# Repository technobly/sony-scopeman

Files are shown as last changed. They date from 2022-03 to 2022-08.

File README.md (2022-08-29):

# Sony-Scopeman

Hardware Design files of a replacement mainboard for the Sony Watchman FD-10A. This turns it into a bluetooth and Wi-Fi-enabled vector display.

# Features
There are two modes which can be selected via the power switch:

* In "Audio" mode, the ESP32 acts as a bluetooth speaker. Play back audio files from your smartphone or laptop to hear and see the soundwaves. You can change the size by adjusting the playback volume

    [Audio Demo](https://twitter.com/FauthNiklas/status/1337467949318279170)

* In "Video" mode, the ESP32 renders the result of the Lorenz Attractor equation. You can change the simulation speed using the "Tune" knob.

    [Video Demo](https://twitter.com/FauthNiklas/status/1339650704584171522)

# Instructions

You'll need:

* Sony Watchman Model FD-10A
* Pre-assembled replacemend mainboard (eg. from JLCPCB assembly)
* Two 803040 (1000mAh) Lipo batteries with JST-PH 2.0mm connector



Open the Sony Watchman and unscrew the original mainboard. Make sure to keep all the screws in a safe place.



Unsolder all wires from the mainboard.



Unsolder (and unscrew) these components from the mainboard. We'll need them for our replacement.




Your trimmer pots might also be a different style, but check that they are the same 5k ohm value ("502").

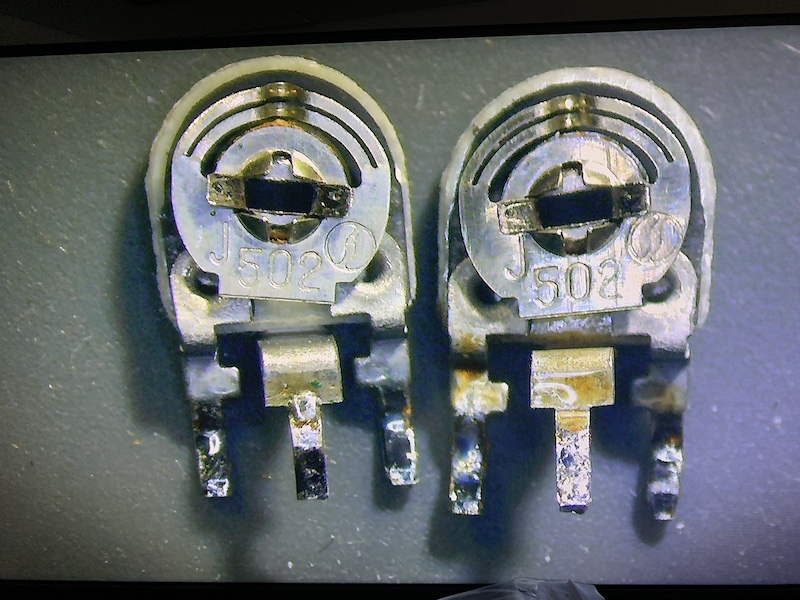
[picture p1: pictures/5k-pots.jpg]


Install all unsoldered components on the replacement mainboard.



Unsolder the speaker cables (black and white) from the flyback PCB. Solder them to the replacement PCB (take care of polarity. White is closer to the ESP32).
Remove all other cables from the flyback PCB except for blue, yellow, black and purple.



Your speaker wires might not be black and white, but both black.  There is a polarity of the speaker, and the positive (+) was marked with red paint/glyptol.  You might also have to extend your speaker wires.

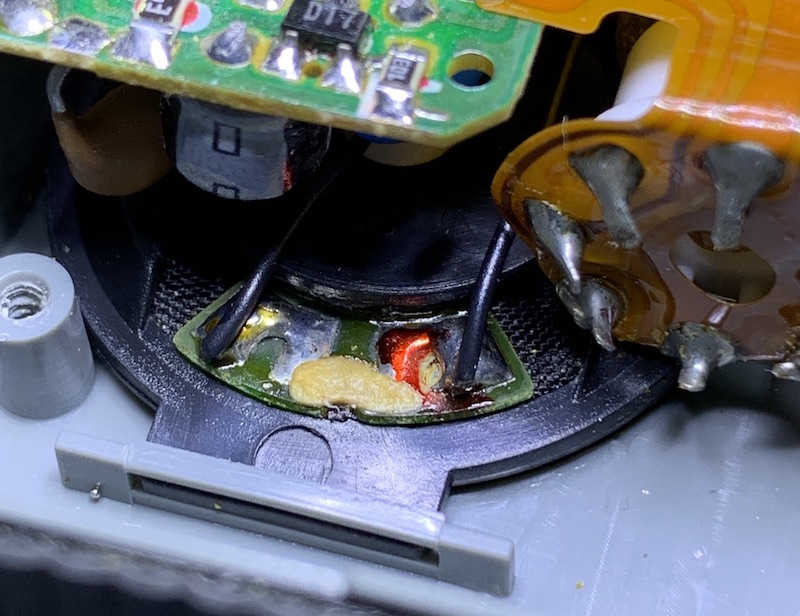
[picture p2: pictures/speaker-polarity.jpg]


Solder the blue (flyback signal) and yellow (blanking) to the new mainboard.
Do the same for purple (supply) and black (GND).



Next, connect the deflection coil wires (purple, white, red and blue). 



Here are more pictures of the assembled unit.
:mag: CLICK FOR A LARGER IMAGE!

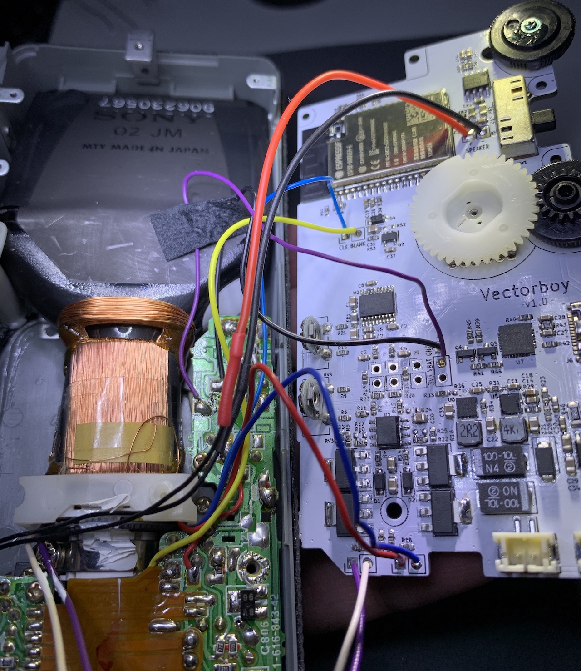
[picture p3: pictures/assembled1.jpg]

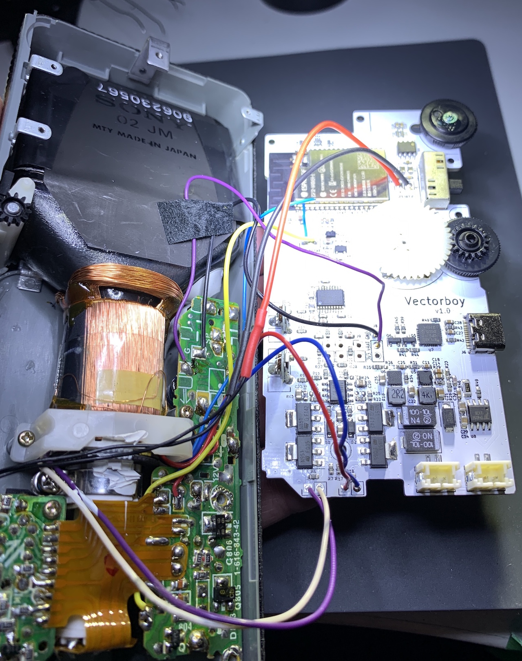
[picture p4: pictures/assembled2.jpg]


:pencil2: If you want to slowly bring up your board and not let the magic smoke out, here are some things you can do:

- Use a current limited power supply and make a cable that plugs into the JST2.0 connector.  Set your power supply to 4V at 500mA.
- When the device normally powers on it draws about 300mA.  If it draws 500mA you probably have a short circuit somewhere.
- Check the +3.3V output (it should be about +3.3V)
- Check the -3.3V output (it should be about -3.7V)
- :warning: Check the FLYBACK output, it should be toggling at 16kHz @ 40% duty cycle.  If it's continuously LOW, it will make the power supply draw infinite amounts of current.  It should be pulled up to +3.3V when the ESP32 is reset/programming via R50.

You'll proabably want to play with it for a while and make sure everything is working well before moving on to the final steps.

You can now plug in the batteries (make sure the watchman is turned off) and screw the mainboard back in place. You need two screws for this (mind the arrows on the back of the PCB).


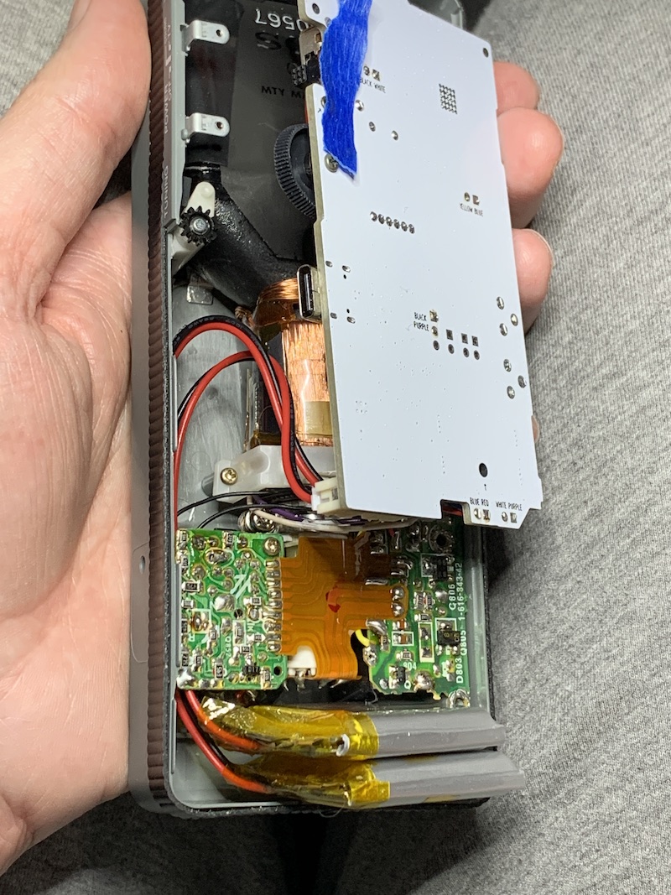
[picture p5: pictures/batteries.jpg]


Now you can add a slothole to the lower half of the case for the USB type C jack. You also need to brake away some plastics to make space for the new batteries. No worries, if done correctly this won't be visible from the outside and the battery cover will still close.

Something really handy for these mods is the [Dremel 1/16" ballnose cutter (#109)](https://www.amazon.com/Dremel-109-Engraving-Cutter-16-inch/dp/B0006N72X4).  I got mine in an [11 piece Carving/Engraving Kit](https://www.amazon.com/Dremel-729-01-Engraving-Accessories-11-Piece/dp/B09FP387V2).  This is also really good for the USB-C cut-out.


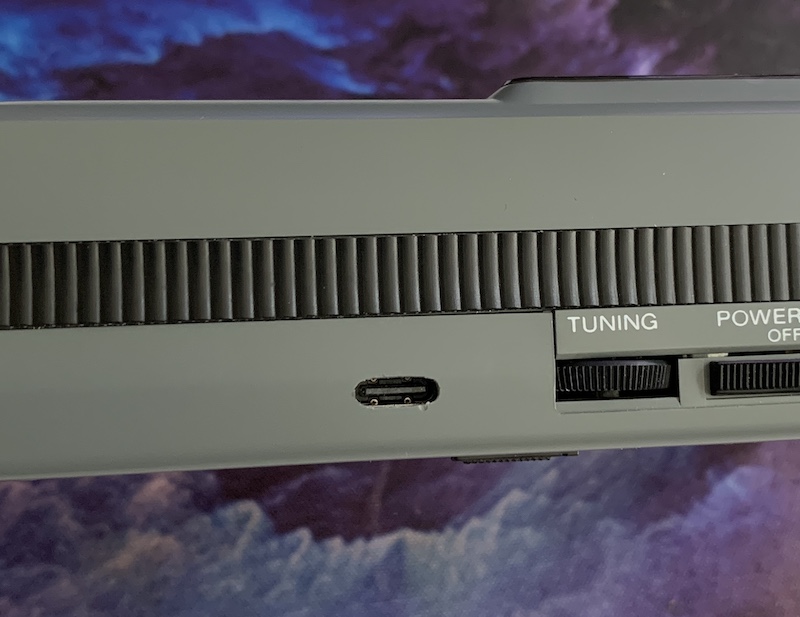
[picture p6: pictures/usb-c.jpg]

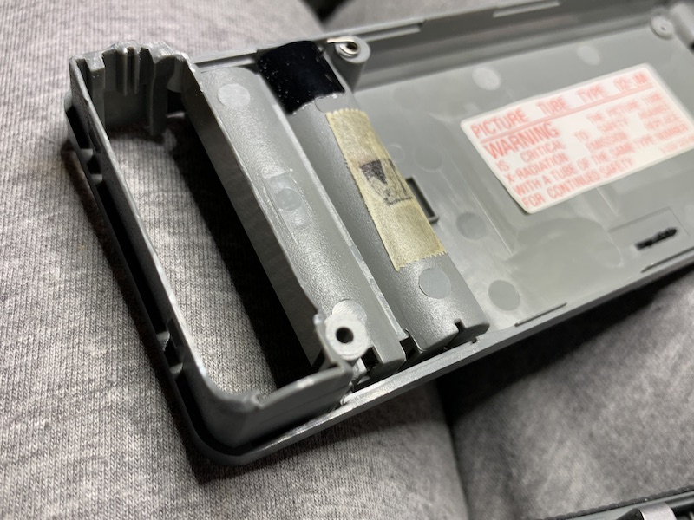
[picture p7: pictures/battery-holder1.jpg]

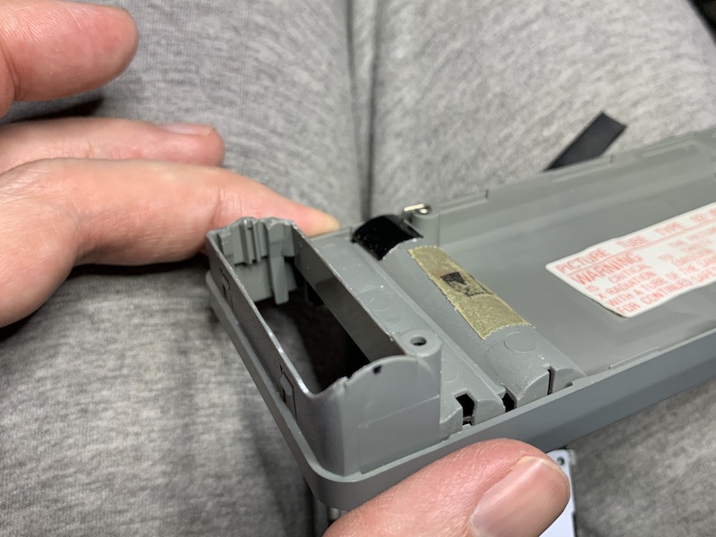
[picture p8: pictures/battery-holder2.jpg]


That's it! Before you screw the watchman back together and store the batteries behind the cover, you may want to adjust the two potentiometers on the mainboard to center the image. But first you need to flash the firmware. Turn on the watchman and connect it via USB. You can then flash the ESP32 using the Arduino IDE (make sure to select "Board: ESP Wrover Module").

You might also need to readjust the focus. This can be done from outside using the original focus knob (hidden behind a small hole at the side).


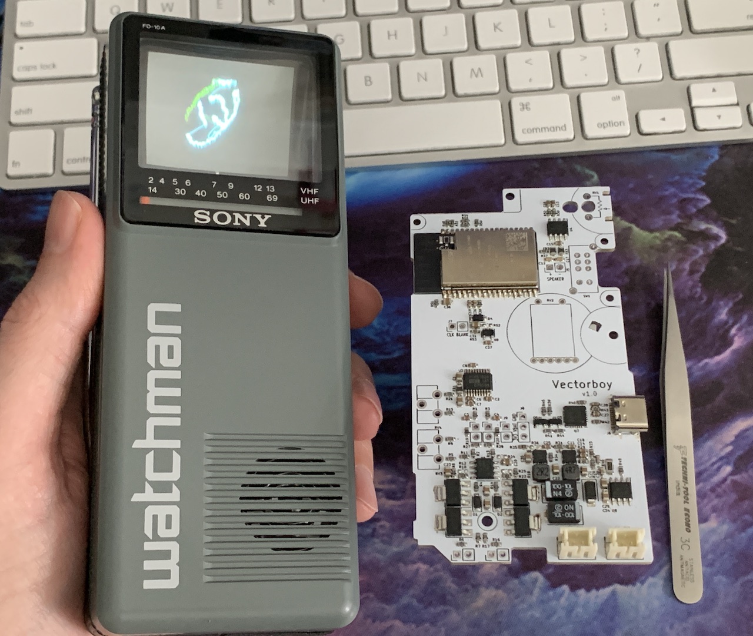
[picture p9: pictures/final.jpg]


# Credits

Deflection coil drivers inspired by http://www.e-basteln.de/file/asteroids/Vectrex_XY_Driver.pdf

A2DP Arduino lib for ESP32: https://github.com/pschatzmann/ESP32-A2DP

# Ordering

See the [BOM README.md](hardware/bom-vectorboy-v1.3/README.md)

:warning: **NOTE: Be sure to order the PCB thinner than standard, 0.040" (1.0mm) should be good.**  If you end up ordering as 0.062" (1.6mm), [you will have to make a bunch of modifications, but it can be done.](hardware/bom-vectorboy-v1.3/thick-pcb-mods.md)

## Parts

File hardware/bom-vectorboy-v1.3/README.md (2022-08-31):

# Vectorboy v1.3 PCB & BOM

Everything you need to order parts for your Sony Scopeman / Vectorboy!

## PCB

:warning: **NOTE: Be sure to order the PCB thinner than standard, 0.040" (1.0mm) should be good.**  If you end up ordering as 0.062" (1.6mm), [you will have to make a bunch of modifications, but it can be done.](thick-pcb-mods.md)

### JLCPCB

All parts including PCB's for 2 complete boards was $159.82 ($80 each).

I got a brand new Sony Watchman FD-10A from eBay for $30 shipped.

I made some minor tweaks to the silkscreen and ordered PCBs from JLCPCB.

- Added "JLCJLCJLCJLC" to the back side of the PCB for part number placement
- Moved "PURPLE / BLACK" text for readability
- Changed main text to say "Vectorboy v1.0" for fun and motivation
- I ordered 20 PCBs in White soldermask with Black silkscreen with a stencil for $34.38 shipped.

Order PCB's by using the included [gerbers-vectorboy-v1.3.zip](../gerber-vectorboy-v1.3/) and uploading those with all of the necessary specs [JLCPCB](https://jlcpcb.com)

Centroid/Position data [is here](../gerber-vectorboy-v1.3/pos.csv) for ordering assembled boards.  (Note: I have not used this file myself, just trying to keep it updated from the original)

## BOM

### LCSC

Most of the parts are included in [LCSC-Bom-Vectorboy-v1.3.csv](LCSC-Bom-Vectorboy-v1.3.csv)

However, some of those parts were out of stock and I had to get them at Digikey or eBay.

Here is the exact order that was exported

- [LCSC-Exported-Vectorboy-v1.3.csv](LCSC-Exported-Vectorboy-v1.3.csv) - $33.14

To import this:

- Upload the CSV to [LCSC's BOM Tool](https://lcsc.com/bom)
- Set the columns for "LCSC Part Number", "Customer Part Number" (these are the ref des.), "Quantity"
- This will add enough parts for 2 complete boards (adjust as necessary)

> NOTE: if you plan to build these by hand, you might want to import the [LCSC-Exported-Condensed-Designators-Vectorboy-v1.3.csv](LCSC-Exported-Condensed-Designators-Vectorboy-v1.3.csv) BOM which has Condensed Designators in decending order (e.g. "C37,30,28-25,19,14,11,8,2") that will fit on the bags of parts you'll receive.  DO NOT use this one if you are planning on having JLCPCB assemble your boards for you.

### Digikey

A few parts needed to be ordered from Digikey

- [Here's the shared cart](https://www.digikey.com/short/332bzwh8) - $44.50

### eBay

Grumble grumble, part shortage... get these at eBay

- [TPS63001DRCR](https://www.ebay.com/itm/265393777178) - $12.98
- [TPS63700DRCR](https://www.ebay.com/itm/223277053580) - $18.37

## Batteries

Don't forget the batteries!

- [803040](https://www.amazon.com/1000mAh-Battery-Rechargeable-Lithium-Connector/dp/B09FFGP6N5) - $16.44

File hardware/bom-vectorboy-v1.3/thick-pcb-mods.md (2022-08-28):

# Thick PCB Mods

**NOTE: These are the modifications required if you ended up ordering the PCB as a standard size 0.0625" (1.6mm).  If you have a thinner PCB 0.040" (1.0mm) you won't require these mods.**

This little tab on the volume knob probably won't fit all of the way through the PCB because it is thicker than the original.  You can trim the hook part off.

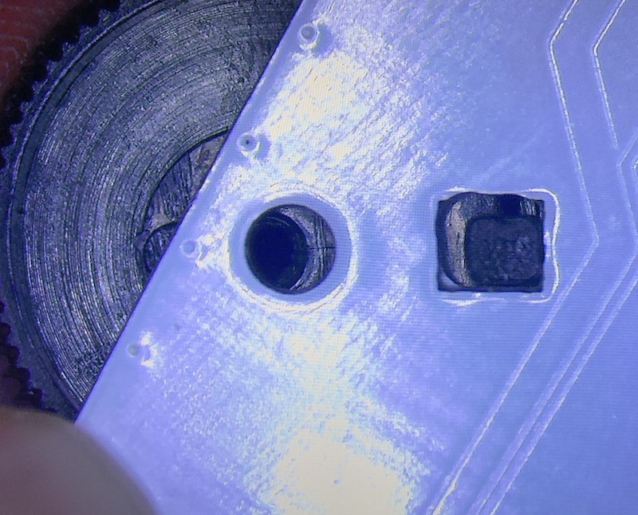
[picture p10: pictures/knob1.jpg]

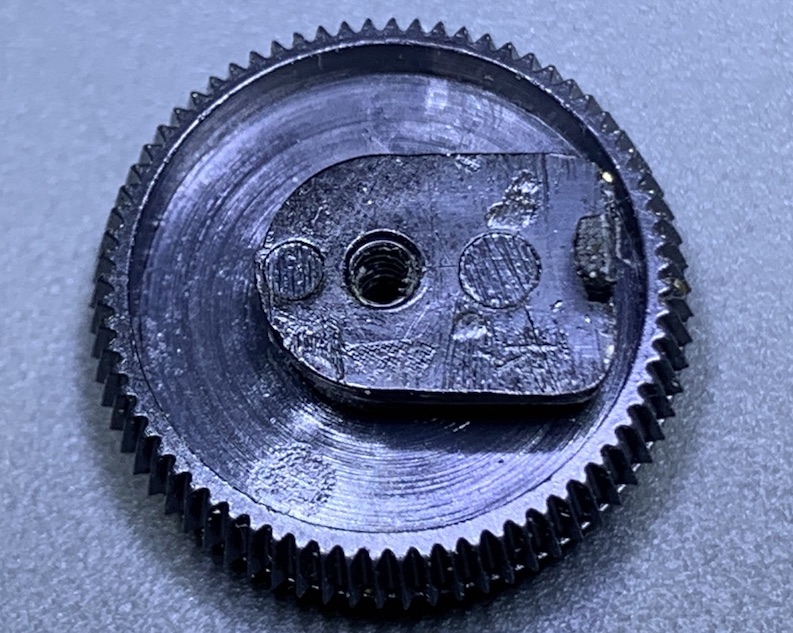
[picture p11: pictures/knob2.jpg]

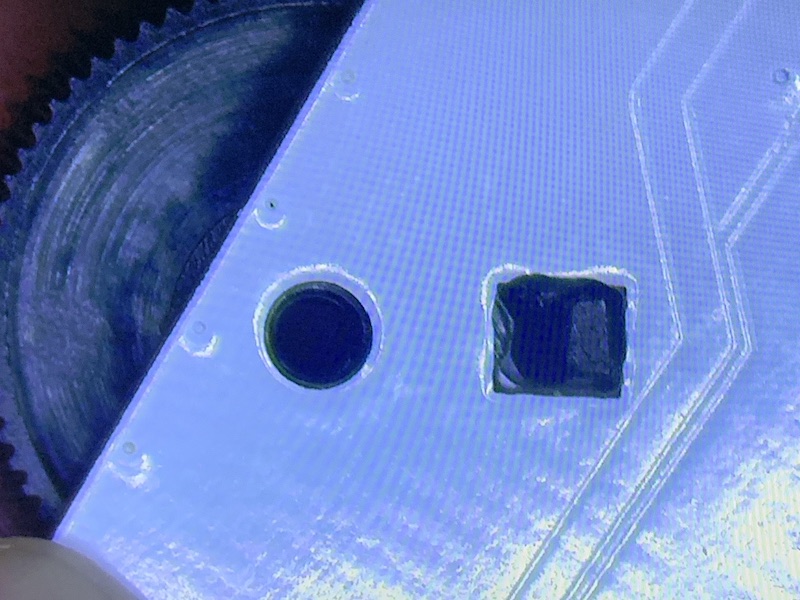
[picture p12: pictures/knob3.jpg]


You will have to recess this screw to get enough of the threads to engage.

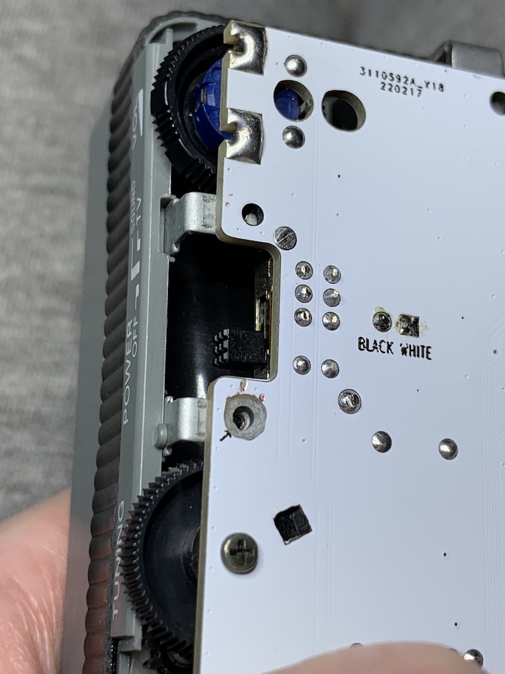
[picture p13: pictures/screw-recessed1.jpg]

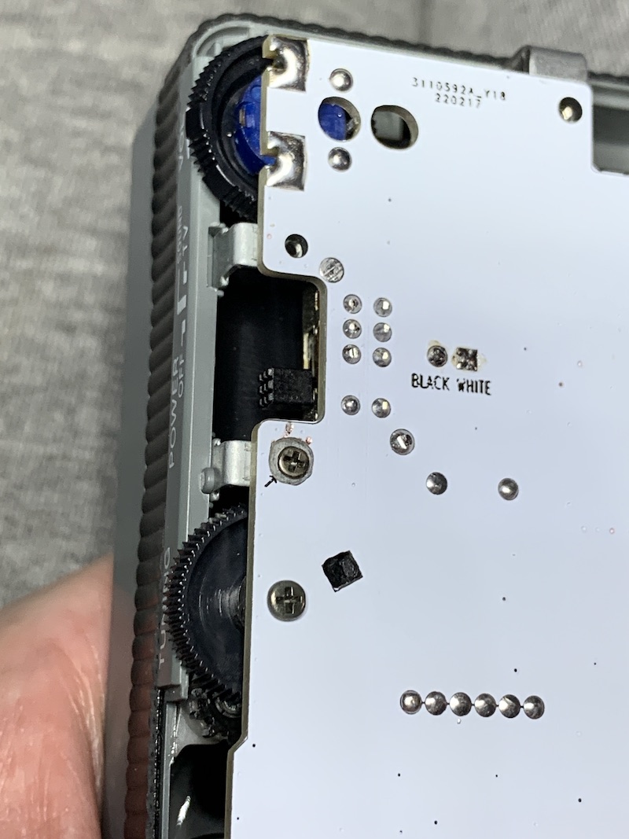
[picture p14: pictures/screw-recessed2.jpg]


You will have to recess the area of the PCB that the antenna rests on.  This is also critical to get enough threads to engage and pull the enclosure together tightly.

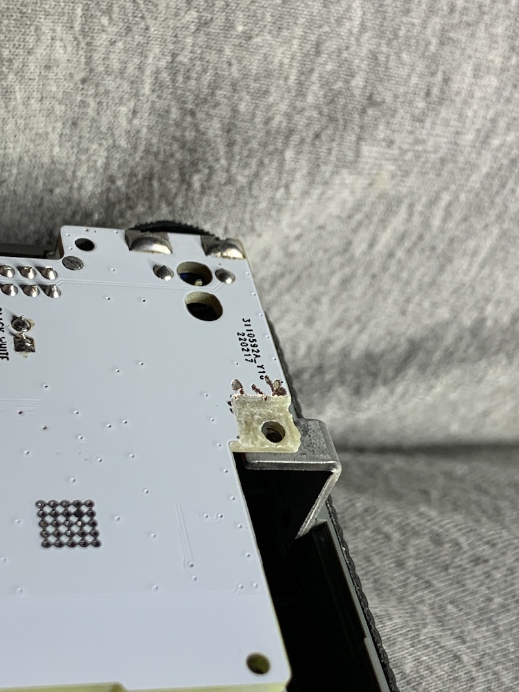
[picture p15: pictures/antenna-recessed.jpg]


The case back bosses need to have 1.0mm of material removed from them.  This is what they look like before modification (sorry I forgot to take a picture after modding... I did this on my CNC machine, but could easily be done with a dremel tool)

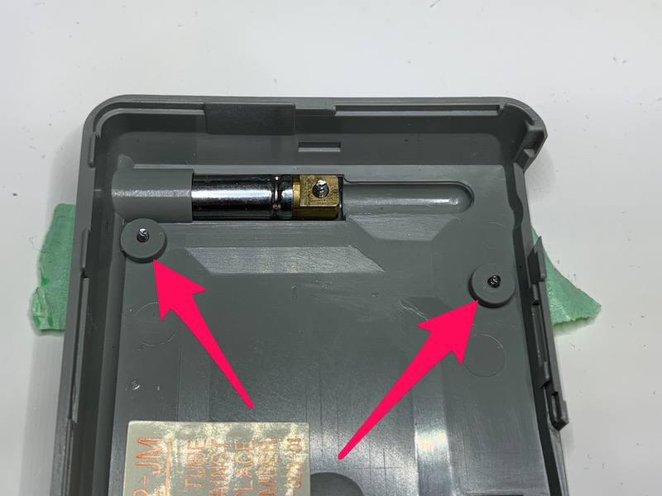
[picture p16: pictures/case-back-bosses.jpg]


Something really handy for these mods is the [Dremel 1/16" ballnose cutter (#109)](https://www.amazon.com/Dremel-109-Engraving-Cutter-16-inch/dp/B0006N72X4).  I got mine in an [11 piece Carving/Engraving Kit](https://www.amazon.com/Dremel-729-01-Engraving-Accessories-11-Piece/dp/B09FP387V2).

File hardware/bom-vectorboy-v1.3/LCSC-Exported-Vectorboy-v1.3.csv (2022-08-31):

LCSC Part Number | Manufacture Part Number | Manufacturer | Customer NO. | Package | Description | RoHS | Order Qty. | Min\Mult Order Qty. | Unit Price | Order Price
C1017 | GZ2012D601TF | Sunlord | FB3,FB2,FB1 | 0805 | 500mA 1 300mΩ 600Ω@100MHz ±25% 0805 Ferrite Beads ROHS | YES | 50 | 50\50 | $0.019200 | $0.96
C1603 | CL10B221KB8NNNC | Samsung Electro-Mechanics | C17,C12 | 0603 | 50V 220pF X7R ±10% 0603 Multilayer Ceramic Capacitors MLCC - SMD/SMT ROHS | YES | 50 | 50\50 | $0.006400 | $0.32
C1604 | 0603B222K500NT | FH(Guangdong Fenghua Advanced Tech) | C4,C3 | 0603 | 50V 2.2nF X7R ±10% 0603 Multilayer Ceramic Capacitors MLCC - SMD/SMT ROHS | YES | 100 | 100\100 | $0.003000 | $0.30
C1634 | CL10C100JB8NNNC | Samsung Electro-Mechanics | C10 | 0603 | 50V 10pF C0G ±5% 0603 Multilayer Ceramic Capacitors MLCC - SMD/SMT ROHS | YES | 50 | 50\50 | $0.005700 | $0.29
C1691 | CL10A106MQ8NNNC | Samsung Electro-Mechanics | C15 | 0603 | 6.3V 10uF X5R ±20% 0603 Multilayer Ceramic Capacitors MLCC - SMD/SMT ROHS | YES | 50 | 50\50 | $0.006600 | $0.33
C6568 | CP2102-GMR | SILICON LABS | U7 | QFN-28_5x5x05P | Transceiver 1Mbps USB 1/1 QFN-28_5x5x05P USB ICs ROHS | YES | 2 | 1\1 | $3.649900 | $7.30
C8678 | SS34 | MDD（Microdiode Electronics） | D3 | SMA(DO-214AC) | 40V 550mV@3A 3A SMA(DO-214AC) Schottky Barrier Diodes (SBD) ROHS | YES | 10 | 10\10 | $0.047600 | $0.48
C14663 | CC0603KRX7R9BB104 | YAGEO | C37,C30,C28,C27,C26,C25,C19,C14,C11,C8,C2 | 0603 | 50V 100nF X7R ±10% 0603 Multilayer Ceramic Capacitors MLCC - SMD/SMT ROHS | YES | 100 | 100\100 | $0.002800 | $0.28
C15849 | CL10A105KB8NNNC | Samsung Electro-Mechanics | C16,C13 | 0603 | 50V 1uF X5R ±10% 0603 Multilayer Ceramic Capacitors MLCC - SMD/SMT ROHS | YES | 50 | 50\50 | $0.006000 | $0.30
C95841 | CL21B106KOQNNNE | Samsung Electro-Mechanics | C36,C35,C34,C31,C29,C24,C23,C22,C21,C20,C9,C5,C1 | 0805 | 16V 10uF X7R ±10% 0805 Multilayer Ceramic Capacitors MLCC - SMD/SMT ROHS | YES | 40 | 20\20 | $0.030900 | $1.24
C16581 | TP4056-42-ESOP8 | TOPPOWER(Nanjing Extension Microelectronics) | U8 | ESOP-8 | ESOP-8 Battery Management ICs ROHS | YES | 2 | 1\1 | $0.252000 | $0.50
C21189 | 0603WAF0000T5E | UNI-ROYAL(Uniroyal Elec) | R35,R20,R19 | 0603 | ±1% 1/10W Thick Film Resistors 75V -55℃~+155℃ 0Ω 0603 Chip Resistor - Surface Mount ROHS | YES | 100 | 100\100 | $0.001300 | $0.13
C21190 | 0603WAF1001T5E | UNI-ROYAL(Uniroyal Elec) | R55,R54,R53,R17,R13,R7,R2 | 0603 | ±1% 1/10W Thick Film Resistors 75V ±100ppm/℃ -55℃~+155℃ 1kΩ 0603 Chip Resistor - Surface Mount ROHS | YES | 100 | 100\100 | $0.001200 | $0.12
C22765 | 0603WAF1201T5E | UNI-ROYAL(Uniroyal Elec) | R49 | 0603 | ±1% 1/10W Thick Film Resistors 75V ±100ppm/℃ -55℃~+155℃ 1.2kΩ 0603 Chip Resistor - Surface Mount ROHS | YES | 100 | 100\100 | $0.001500 | $0.15
C22775 | 0603WAF1000T5E | UNI-ROYAL(Uniroyal Elec) | R34,R32,R30 | 0603 | ±1% 1/10W Thick Film Resistors 75V ±200ppm/℃ -55℃~+155℃ 100Ω 0603 Chip Resistor - Surface Mount ROHS | YES | 100 | 100\100 | $0.001400 | $0.14
C22859 | 0603WAF100JT5E | UNI-ROYAL(Uniroyal Elec) | R31,R14,R4 | 0603 | ±1% 1/10W Thick Film Resistors 75V ±400ppm/℃ -55℃~+155℃ 10Ω 0603 Chip Resistor - Surface Mount ROHS | YES | 100 | 100\100 | $0.001400 | $0.14
C2849052 | HPCR0603F4R70S9 | Resistor.Today | R18,R8 | 0603 | ±1% 0.2W 4.7Ω 0603 Chip Resistor - Surface Mount ROHS | YES | 50 | 50\50 | $0.010900 | $0.55
C22961 | 0603WAF2203T5E | UNI-ROYAL(Uniroyal Elec) | R26 | 0603 | ±1% 1/10W Thick Film Resistors 75V ±100ppm/℃ -55℃~+155℃ 220kΩ 0603 Chip Resistor - Surface Mount ROHS | YES | 100 | 100\100 | $0.001400 | $0.14
C22978 | 0603WAF3301T5E | UNI-ROYAL(Uniroyal Elec) | R16,R6 | 0603 | ±1% 1/10W Thick Film Resistors 75V ±100ppm/℃ -55℃~+155℃ 3.3kΩ 0603 Chip Resistor - Surface Mount ROHS | YES | 100 | 100\100 | $0.001400 | $0.14
C23179 | 0603WAF4700T5E | UNI-ROYAL(Uniroyal Elec) | R22,R11,R10,R3,R1 | 0603 | ±1% 1/10W Thick Film Resistors 75V ±100ppm/℃ -55℃~+155℃ 470Ω 0603 Chip Resistor - Surface Mount ROHS | YES | 100 | 100\100 | $0.001400 | $0.14
C23186 | 0603WAF5101T5E | UNI-ROYAL(Uniroyal Elec) | R43,R42 | 0603 | ±1% 1/10W Thick Film Resistors 75V ±100ppm/℃ -55℃~+155℃ 5.1kΩ 0603 Chip Resistor - Surface Mount ROHS | YES | 100 | 100\100 | $0.001400 | $0.14
C23345 | 0603WAF220JT5E | UNI-ROYAL(Uniroyal Elec) | R51 | 0603 | ±1% 1/10W Thick Film Resistors 75V ±100ppm/℃ -55℃~+155℃ 22Ω 0603 Chip Resistor - Surface Mount ROHS | YES | 100 | 100\100 | $0.001500 | $0.15
C23630 | CL10A225KO8NNNC | Samsung Electro-Mechanics | C7,C6 | 0603 | 16V 2.2uF X5R ±10% 0603 Multilayer Ceramic Capacitors MLCC - SMD/SMT ROHS | YES | 50 | 50\50 | $0.006400 | $0.32
C308471 | MCR18EZHFLR270 | ROHM Semicon | R46 | 1206 | 250mW 0.27Ω ±250ppm/℃ ±1% 1206 Current Sense Resistors/Shunt Resistors ROHS | YES | 10 | 10\10 | $0.070200 | $0.70
C25803 | 0603WAF1003T5E | UNI-ROYAL(Uniroyal Elec) | R48,R38,R37,R33,R23 | 0603 | ±1% 1/10W Thick Film Resistors 75V ±100ppm/℃ -55℃~+155℃ 100kΩ 0603 Chip Resistor - Surface Mount ROHS | YES | 100 | 100\100 | $0.001200 | $0.12
C25804 | 0603WAF1002T5E | UNI-ROYAL(Uniroyal Elec) | R50,R45,R44,R41,R40,R39 | 0603 | ±1% 1/10W Thick Film Resistors 75V ±100ppm/℃ -55℃~+155℃ 10kΩ 0603 Chip Resistor - Surface Mount ROHS | YES | 100 | 100\100 | $0.001400 | $0.14
C18671 | 0603WAJ0753T5E | UNI-ROYAL(Uniroyal Elec) | R29 | 0603 | ±5% 1/10W Thick Film Resistors 75V ±100ppm/℃ -55℃~+155℃ 75kΩ 0603 Chip Resistor - Surface Mount ROHS | YES | 100 | 100\100 | $0.001300 | $0.13
C31850 | 0603WAF2202T5E | UNI-ROYAL(Uniroyal Elec) | R28,R27,R21,R15,R9,R5 | 0603 | ±1% 1/10W Thick Film Resistors 75V ±100ppm/℃ -55℃~+155℃ 22kΩ 0603 Chip Resistor - Surface Mount ROHS | YES | 100 | 100\100 | $0.001400 | $0.14
C53987 | 0603B472K500NT | FH(Guangdong Fenghua Advanced Tech) | C18 | 0603 | 50V 4.7nF X7R ±10% 0603 Multilayer Ceramic Capacitors MLCC - SMD/SMT ROHS | YES | 100 | 100\100 | $0.003100 | $0.31
C81598 | 1N4148W | ST(Semtech) | D4,D2,D1 | SOD-123 | 75V +150℃@(Tj) 400mW Single 1.25V@150mA 4ns 1μA@75V 150mA SOD-123 Switching Diode ROHS | YES | 50 | 50\50 | $0.014300 | $0.72
C111113 | MMBT3904 | Shikues | Q5,Q6 | SOT-23(SOT-23-3) | 40V 225mW 200mA NPN SOT-23(SOT-23-3) Bipolar Transistors - BJT ROHS | YES | 50 | 50\50 | $0.012200 | $0.61
C112137 | PAM8302AADCR | Diodes Incorporated | U4 | SOP-8_150mil | 2.5W x 1 @ 4Ω 2V ~ 5.5V 1-Channel (Mono) Class D SOP-8_150mil Audio Power OpAmps ROHS | YES | 2 | 1\1 | $0.388600 | $0.78
C133359 | STN851 | STMicroelectronics | Q1,Q3 | SOT-223 | 60V 1.6W 5A 25@10A,1V 130MHz 350mV@5A,200mA NPN +150℃@(Tj) SOT-223 Bipolar Transistors - BJT ROHS | YES | 4 | 1\1 | $0.338300 | $1.35
C133360 | STN951 | STMicroelectronics | Q2,Q4 | SOT-223 | 60V 1.6W 5A 25@10A,1V 130MHz 350mV@5A,200mA PNP +150℃@(Tj) SOT-223 Bipolar Transistors - BJT ROHS | YES | 4 | 1\1 | $0.338300 | $1.35
C155463 | 293D107X9010D2TE3 | Vishay Intertech | C33,C32 | CASE-D_7343 | 100uF 10V -55℃~+125℃ 600mΩ@100kHz ±10% CASE-D_7343 Tantalum Capacitors ROHS | YES | 4 | 1\1 | $0.510400 | $2.04
C265003 | B2B-PH-SM4-TBT(LF)(SN) | JST Sales America | BT1,BT2 | Plugin,P=2mm | 1x2P PH 1 2mm 2 Copper Alloy Plugin,P=2mm Wire To Board / Wire To Wire Connector ROHS | YES | 4 | 1\1 | $0.423800 | $1.70
C165948 | TYPE-C-31-M-12 | Korean Hroparts Elec | J6 | SMD | 250mA 1 16 Female Type-C SMD USB Connectors ROHS | YES | 2 | 1\1 | $0.358900 | $0.72
C520302 | CR4018-2R2M | Ceaiya | L2 | SMD | 2A 2.2uH ±20% 44mΩ SMD Power Inductors ROHS | YES | 10 | 10\10 | $0.052200 | $0.52
C520304 | CR4018-4R7M | Ceaiya | L1 | SMD | 1.7A 4.7uH ±20% 90mΩ SMD Power Inductors ROHS | YES | 10 | 10\10 | $0.050800 | $0.51
C686637 | LMV321 | PJSEMI | U9 | SOT-23-5 | SOT-23-5 Operational Amplifier ROHS | YES | 5 | 5\5 | $0.086400 | $0.43

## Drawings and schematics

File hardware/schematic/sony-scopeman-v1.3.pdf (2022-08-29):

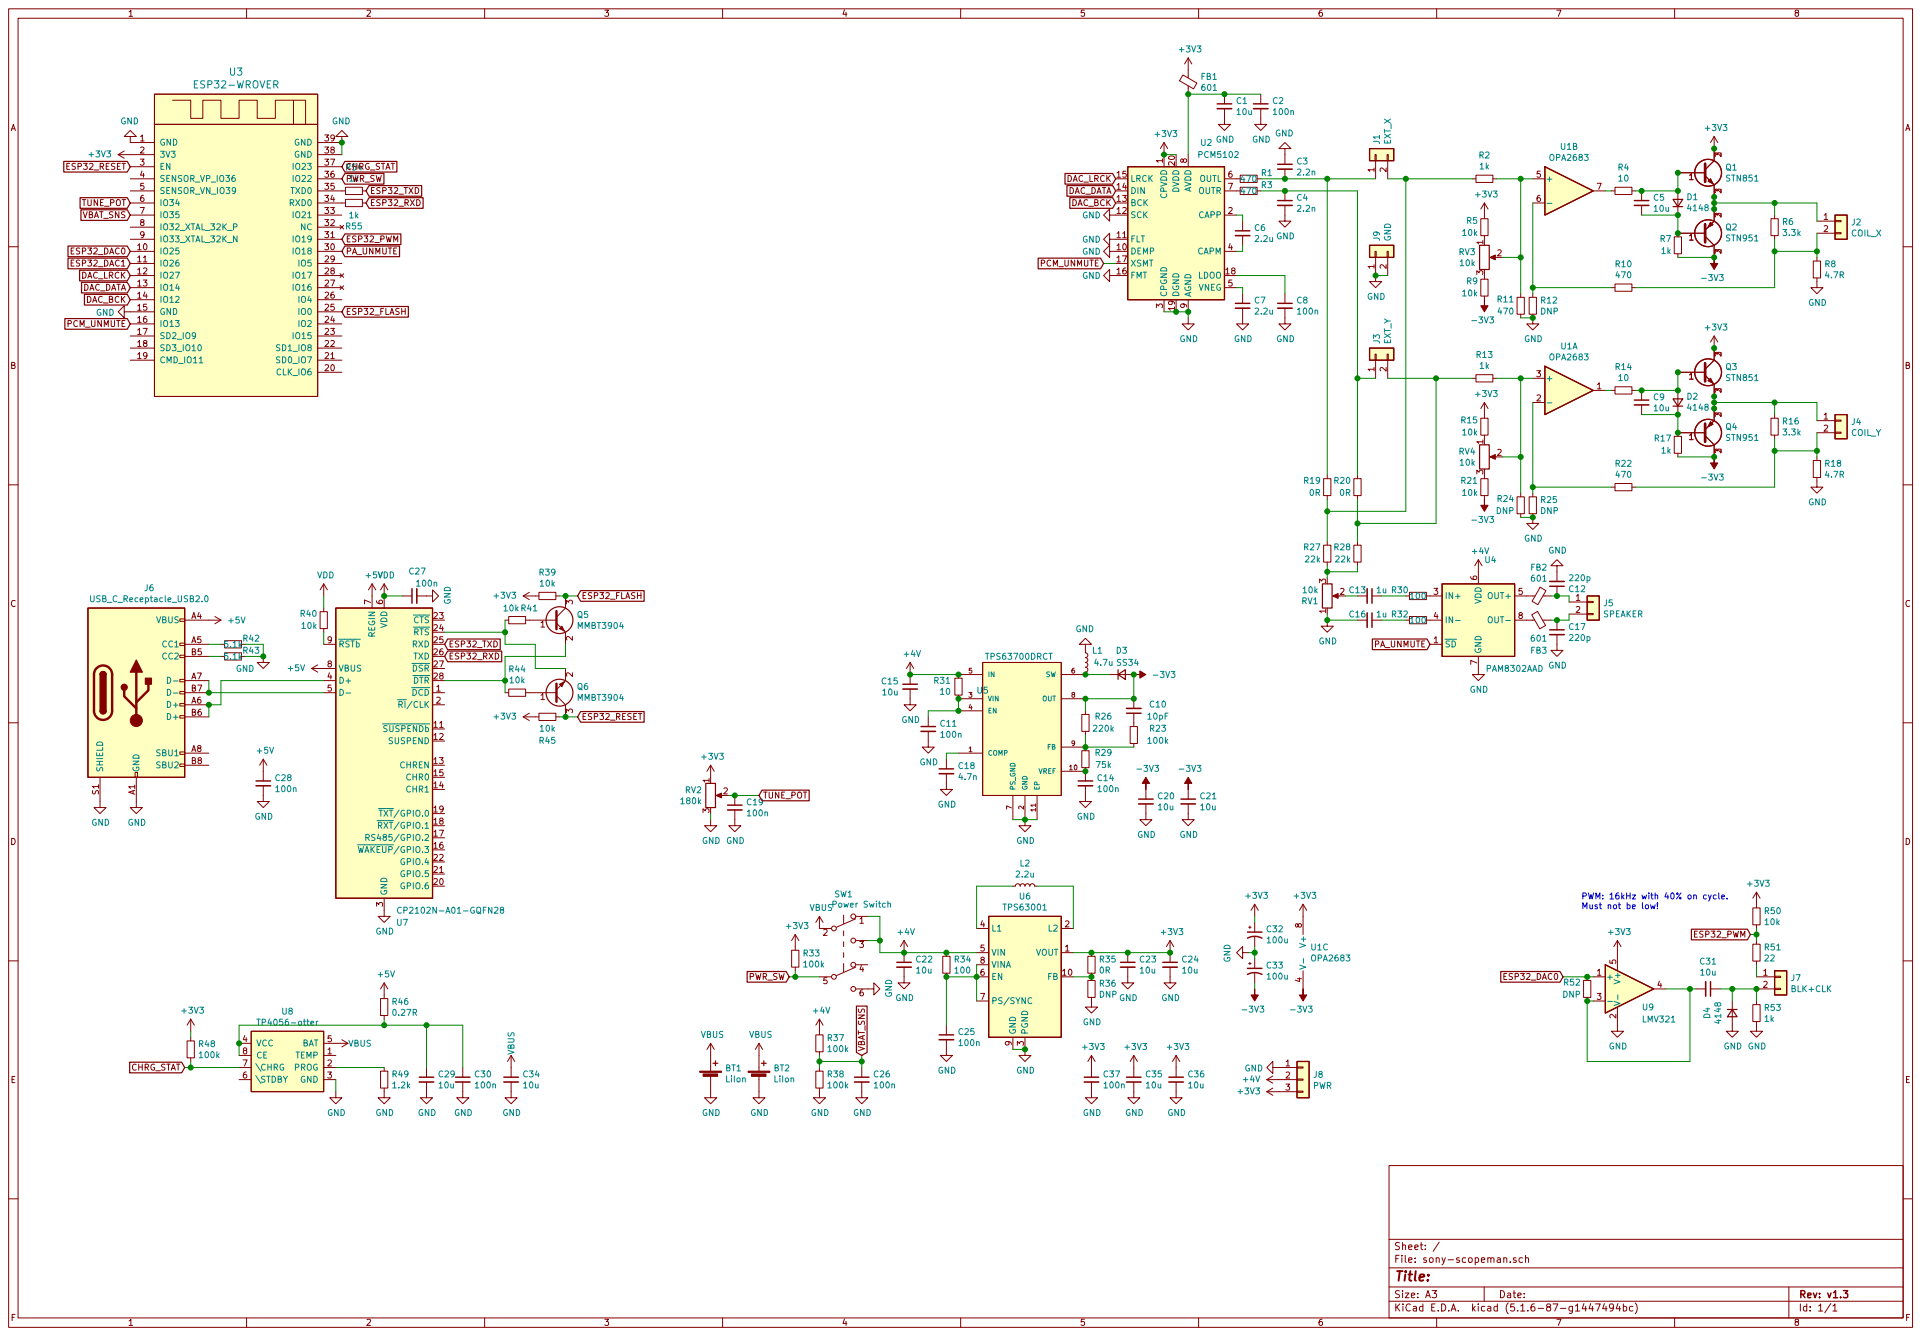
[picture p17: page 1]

1 DEMP 10 FLT 11 SCK 12 BCK 13 DIN 14

3 CAPM 4 VNEG 5 OUTL 6 OUTR 7 AVDD

7 VBUS 8 RSTb 9 U7CP2102N-A01-GQFN28 GND A1 VBUS A4 CC1 A5 D+ A6 D- A7 SBU1 A8 CC2 B5 D+ B6 D- B7 SBU2 B8 SHIELD S1

PWM: 16kHz with 40% on cycle. Must not be low!
+3V3 GNDV- 2 V+

File: sony-scopeman.sch Sheet: /

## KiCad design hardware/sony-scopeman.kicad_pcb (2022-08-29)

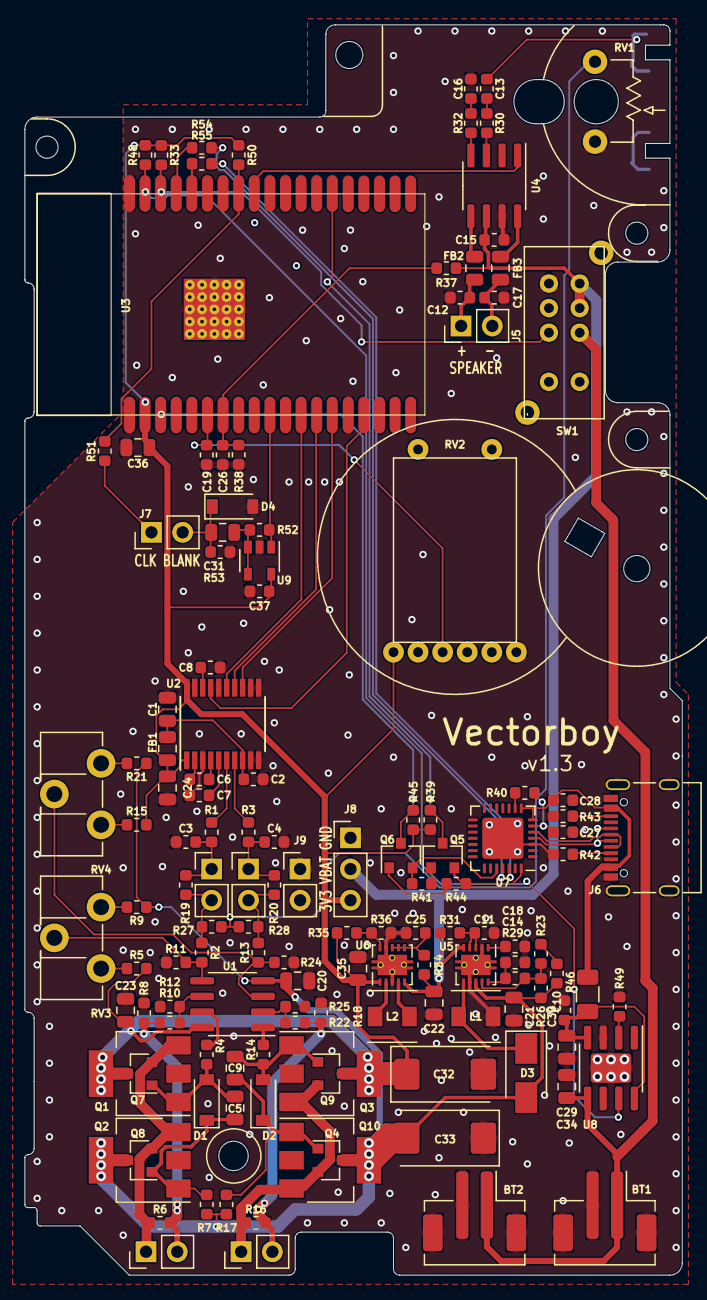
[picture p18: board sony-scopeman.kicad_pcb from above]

Board: 2 copper layers, 53.5 x 101.8 mm, 135 parts (0 on the bottom side), 87 nets.

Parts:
BT1, BT2: LiIon; JST_PH_B2B-PH-SM4-TB_1x02-1MP_P2.00mm_Vertical
C1, C5, C9, C20, C21, C22, C23, C24, C29, C31, C34, C35, C36: 10u; C_0805_2012Metric
C2, C8, C11, C14, C19, C25, C26, C27, C28, C30, C37: 100n; C_0603_1608Metric
C3, C4: 2.2n; C_0603_1608Metric
C6, C7: 2.2u; C_0603_1608Metric
C10: 10pF; C_0603_1608Metric
C12, C17: 220p; C_0603_1608Metric
C13, C16: 1u; C_0603_1608Metric
C15: 10u; C_0603_1608Metric
C18: 4.7n; C_0603_1608Metric
C32, C33: 100u; CP_EIA-7343-43_Kemet-X
D1, D2, D4: 4148; D_SOD-123
D3: SS34; D_SMA
FB1, FB2, FB3: 601; L_0805_2012Metric
J1: EXT_X; PinHeader_1x02_P2.54mm_Vertical
J2: COIL_X; PinHeader_1x02_P2.54mm_Vertical
J3: EXT_Y; PinHeader_1x02_P2.54mm_Vertical
J4: COIL_Y; PinHeader_1x02_P2.54mm_Vertical
J5: SPEAKER; PinHeader_1x02_P2.54mm_Vertical
J6: USB_C_Receptacle_USB2.0; USB_C_Receptacle_Palconn_UTC16-G
J7: BLK+CLK; PinHeader_1x02_P2.54mm_Vertical
J8: PWR; PinHeader_1x03_P2.54mm_Vertical
J9: GND; PinHeader_1x02_P2.54mm_Vertical
L1: 4.7u; Inductor_4040
L2: 2.2u; Inductor_4040
Q1, Q3: PZT3904; SOT-223-3_TabPin2
Q2, Q4: PZT3906; SOT-223-3_TabPin2
Q5, Q6: MMBT3904; SOT-23
Q7, Q9: STN851; SOT-23
Q8, Q10: STN951; SOT-23
R1, R3, R10, R11, R22: 470; R_0603_1608Metric
R2, R7, R13, R17, R54, R55: 1k; R_0603_1608Metric
R4, R14, R31: 10; R_0603_1608Metric
R5, R9, R15, R21, R39, R40, R41, R44, R45, R50: 10k; R_0603_1608Metric
R6, R16: 3.3k; R_0603_1608Metric
R8, R18: 4.7R; R_0603_1608Metric
R12, R24, R25, R36, R52: DNP; R_0603_1608Metric
R19, R20, R35: 0R; R_0603_1608Metric
R23, R33, R37, R38, R48: 100k; R_0603_1608Metric
R26: 220k; R_0603_1608Metric
R27, R28: 22k; R_0603_1608Metric
R29: 75k; R_0603_1608Metric
R30, R32, R34: 100; R_0603_1608Metric
R42, R43: 5.1k; R_0603_1608Metric
R46: 0.27R; R_1206_3216Metric
R49: 1.2k; R_0603_1608Metric
R51: 22; R_0603_1608Metric
R53: TBD; R_0603_1608Metric
RV1: 10k; sony_volume
RV2: 180k; sony_tune
RV3, RV4: 10k; Potentiometer_ACP_CA9-H3,8_Horizontal
SW1: Power Switch; sony_slide_switch
U1: OPA2683; SOIC-8_3.9x4.9mm_P1.27mm
U2: PCM5102; TSSOP-20_4.4x6.5mm_P0.65mm
U3: ESP32-WROVER
U4: PAM8302AAD; SOIC-8_3.9x4.9mm_P1.27mm
U5: TPS63700DRCT; Texas_DRC0010J_ThermalVias
U6: TPS63001; Texas_DRC0010J_ThermalVias
U7: CP2102N-A01-GQFN28; QFN-28-1EP_5x5mm_P0.5mm_EP3.35x3.35mm
U8: TP4056-otter; SOIC-8-1EP_3.9x4.9mm_P1.27mm_EP2.41x3.3mm
U9: LMV321; SOT-23-5

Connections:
+3V3: C23.1, C24.1, C32.1, C35.1, C36.1, C37.1, FB1.1, J8.3, Q1.2, Q3.2, Q7.3, Q9.3, R5.2, R15.2, R33.1, R35.1, R39.2, R45.2, R48.1, R50.1, RV2.1, U1.8, U2.1, U2.20, U3.2, U6.1, U9.5
+4V: C15.1, C22.1, J8.2, R31.2, R34.1, R37.1, SW1.1, SW1.3, U4.6, U5.5, U6.5
+5V: C28.1, J6.A4, J6.A9, J6.B4, J6.B9, R46.1, U7.7, U7.8
-3V3: C10.2, C20.1, C21.1, C33.2, D3.2, Q2.2, Q4.2, Q8.3, Q10.3, R7.1, R9.1, R17.1, R21.1, R26.2, U1.4, U5.8
CHRG_STAT: R48.2, U3.37, U8.7
DAC_BCK: U2.13, U3.14
DAC_DATA: U2.14, U3.13
DAC_LRCK: U2.15, U3.12
ESP32_DAC0: R52.2, U3.10, U9.1
ESP32_FLASH: Q5.3, R39.1, U3.25
ESP32_PWM: R50.2, R51.1, U3.31
ESP32_RESET: Q6.3, R45.1, U3.3
ESP32_RXD: R55.1, U7.26
ESP32_TXD: R54.1, U7.25
GND: BT1.2, BT2.2, C1.2, C2.2, C3.1, C4.2, C7.2, C8.2, C11.2, C12.2, C14.2, C15.2, C16.2, C17.2, C18.2, C19.2, C20.2, C21.2, C22.2, C23.2, C24.2, C25.2, C26.2, C27.2, C28.2, C29.2, C30.2, C32.2, C33.1, C34.2, C35.2, C36.2, C37.2, D4.2, J6.A1, J6.A12, J6.B1, J6.B12, J6.S1, J8.1, J9.1, J9.2, L1.1, R8.2, R11.1, R12.2, R18.2, R24.1, R25.2, R36.2, R38.2, R42.1, R43.1, R49.2, R53.2, RV1.1, RV2.3, SW1.6, U2.3, U2.9, U2.10, U2.11, U2.12, U2.16, U2.19, U3.1, U3.15, U3.38, U3.39, U4.7, U5.2, U5.7, U5.11, U6.3, U6.9, U6.11, U7.3, U7.29, U8.3, U8.9, U9.2
unnamed: C1.1, C2.1, FB1.2, U2.8
unnamed: C3.2, J1.1, R1.1, R19.2
unnamed: C4.1, J3.1, R3.1, R20.2
unnamed: C5.1, D1.2, Q1.1, Q7.1, R4.1
unnamed: C5.2, D1.1, Q2.1, Q8.1, R7.2
unnamed: C6.1, U2.2
unnamed: C6.2, U2.4
unnamed: C7.1, U2.5
unnamed: C8.1, U2.18
unnamed: C9.1, D2.2, Q3.1, Q9.1, R14.1
unnamed: C9.2, D2.1, Q4.1, Q10.1, R17.2
unnamed: C10.1, R23.2
unnamed: C11.1, R31.1, U5.3, U5.4
unnamed: C12.1, FB2.1, J5.1
unnamed: C13.1, R30.2
unnamed: C13.2, RV1.2
unnamed: C14.1, R29.1, U5.10
unnamed: C16.1, R32.2
unnamed: C17.1, FB3.2, J5.2
unnamed: C18.1, U5.1
unnamed: C25.1, R34.2, U6.6, U6.7, U6.8
unnamed: C29.1, C30.1, R46.2, U8.4, U8.8
unnamed: C31.1, D4.1, J7.2, R53.1
unnamed: C31.2, R52.1, U9.3, U9.4
unnamed: D3.1, L1.2, U5.6
unnamed: FB2.2, U4.5
unnamed: FB3.1, U4.8
unnamed: J1.2, R2.2, R19.1, R27.2
unnamed: J2.1, Q1.3, Q2.3, Q7.2, Q8.2, R6.1
unnamed: J2.2, R6.2, R8.1, R10.1
unnamed: J3.2, R13.2, R20.1, R28.2
unnamed: J4.1, Q3.3, Q4.3, Q9.2, Q10.2, R16.1
unnamed: J4.2, R16.2, R18.1, R22.1
unnamed: J6.A5, R42.2
unnamed: J6.A6, J6.B6, U7.4
unnamed: J6.A7, J6.B7, U7.5
unnamed: J6.B5, R43.2
unnamed: J7.1, R51.2
unnamed: L2.1, U6.4
unnamed: L2.2, U6.2
unnamed: Q5.1, R41.1
unnamed: Q5.2, R44.2, U7.28
unnamed: Q6.1, R44.1
unnamed: Q6.2, R41.2, U7.24
unnamed: R1.2, U2.6
unnamed: R3.2, U2.7
unnamed: R4.2, U1.7
unnamed: R5.1, RV3.1
unnamed: R9.2, RV3.3
unnamed: R10.2, R12.1, U1.6
unnamed: R2.1, R11.2, RV3.2, U1.5
unnamed: R13.1, R24.2, RV4.2, U1.3
unnamed: R14.2, U1.1
unnamed: R15.1, RV4.1
unnamed: R21.2, RV4.3
unnamed: R22.2, R25.1, U1.2
unnamed: R23.1, R26.1, R29.2, U5.9
unnamed: R27.1, R28.1, RV1.3
unnamed: R30.1, U4.3
unnamed: R32.1, U4.4
unnamed: R35.2, R36.1, U6.10
unnamed: R40.1, U7.9
unnamed: R49.1, U8.2
unnamed: R54.2, U3.35
unnamed: R55.2, U3.34
PA_UNMUTE: U3.30, U4.1
PCM_UNMUTE: U2.17, U3.16
PWR_SW: R33.2, SW1.5, U3.36
TUNE_POT: C19.1, RV2.2, U3.6
VBAT_SNS: C26.1, R37.2, R38.1, U3.7
VBUS: BT1.1, BT2.1, C34.1, SW1.2, U8.5
VDD: C27.1, R40.2, U7.6

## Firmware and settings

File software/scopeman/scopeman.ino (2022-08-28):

/*
  Driving deflection coils with an external DAC using ESP32

  Copyright (C) 2020-2022 Niklas Fauth, Technobly
  This program is free software: you can redistribute it and/or modify
  it under the terms of the GNU General Public License as published by
  the Free Software Foundation, either version 3 of the License, or
  (at your option) any later version.
  This program is distributed in the hope that it will be useful,
  but WITHOUT ANY WARRANTY; without even the implied warranty of
  MERCHANTABILITY or FITNESS FOR A PARTICULAR PURPOSE.  See the
  GNU General Public License for more details.
  You should have received a copy of the GNU General Public License
  along with this program.  If not, see <http://www.gnu.org/licenses/>.
*/

#include "BluetoothA2DPSink.h"
#include <Arduino.h>
#include "driver/i2s.h"
#include "driver/ledc.h"

BluetoothA2DPSink a2dp_sink;

#define CODEC_EN   13
#define SPEAKER_EN 18
#define FLYBACK    19
#define TUNE       34
#define SWITCH     22 // This changes the mode of operation. 1 = BT Audio; 0 = Lorentz Attractor Simulation
#define BLANK      25 // Blanking pin

#define BUFFER_LEN 400

uint32_t buf[BUFFER_LEN];

int16_t x_buf[BUFFER_LEN];
int16_t y_buf[BUFFER_LEN];
int16_t z_buf[BUFFER_LEN];

int i2s_num = 0;
size_t i2s_bytes_written = 0;

i2s_config_t i2s_config = {
  .mode = (i2s_mode_t) (I2S_MODE_MASTER | I2S_MODE_TX),
  .sample_rate = 48000,
  .bits_per_sample = (i2s_bits_per_sample_t)16,
  .channel_format = I2S_CHANNEL_FMT_RIGHT_LEFT,
  .communication_format = (i2s_comm_format_t) (I2S_COMM_FORMAT_STAND_I2S),
  .intr_alloc_flags = 0, // default interrupt priority
  .dma_buf_count = 2,
  .dma_buf_len = 256,
  .use_apll = false
};

static const i2s_pin_config_t pin_config = {
  .bck_io_num = 12,
  .ws_io_num = 27,
  .data_out_num = 14,
  .data_in_num = I2S_PIN_NO_CHANGE
};

uint32_t calc_buf_pos(int16_t x, int16_t y) { // +/- 1024
    // verticle keystone correction: \ / -> | |
    int32_t x_tmp = 0;
    // int32_t y_tmp = 0;
    x_tmp = int32_t(float(x) * (1.0f - (0.2 * (float(y)/2600.0f))));
    if (x_tmp > 3500) {
        x_tmp = 3500;
    } else if (x_tmp < -3500) {
        x_tmp = -3500;
    }
    x = x_tmp;

    uint16_t x_i = x*2;
    uint16_t y_i = y*2;
    uint32_t buf;
    buf = x_i | y_i << 16;
    return buf;
}

float x = 0.01;
float y, z;

float a = 10.0;//10.;
float b = 28.0;//28.;
float c = 2.667;//2.66;
float dt = 0.015;
float dx, dy, dz;

void fillBuffer(uint16_t sz, float rot) {

  dx = (a * (y - x)) * dt;
  x = x + dx;

  dy = (x * (b - z) - y)  * dt;
  y = y + dy;

  dz = ((x * y) - (c * z)) * dt;
  z = z + dz;

  float scale = 1.3;

  x_buf[sz / 2] = (x * 64) * scale;
  y_buf[sz / 2] = (y * 64) * scale;
  z_buf[sz / 2] = (z * 64 - 1200) * scale;

  //Serial.println(x_buf[sz/2]);

  for (uint16_t i = 0; i < sz / 2; i++) {
    x_buf[i] = x_buf[i + 1];
    y_buf[i] = y_buf[i + 1];
    z_buf[i] = z_buf[i + 1];
  }

  for (uint16_t i = sz / 2 + 1; i < sz; i++) {
    x_buf[i] = x_buf[sz - i];
    y_buf[i] = y_buf[sz - i];
    z_buf[i] = z_buf[sz - i];
  }

  float sin_z = sin(rot);
  float cos_z = cos(rot);

  float sin_x = sin(rot * 0.5);
  float cos_x = cos(rot * 0.5);

  for (uint16_t i = 0; i < sz; i++) {

    // rotate Z axis
    int new_x = x_buf[i] * cos_z - y_buf[i] * sin_z;
    int new_y = x_buf[i] * sin_z + y_buf[i] * cos_z;

    // rotate ZY axis
    new_x = z_buf[i] * cos_x - new_y * sin_x;
    new_y = z_buf[i] * sin_x + new_y * cos_x;

    buf[i] = calc_buf_pos(new_x, new_y - 150);
  }
}

void setup() {
  pinMode(CODEC_EN, OUTPUT);
  digitalWrite(CODEC_EN, HIGH);

  pinMode(SPEAKER_EN, OUTPUT);
  digitalWrite(SPEAKER_EN, HIGH);

  // Just leave BLANK alone for now
  //  pinMode(BLANK, OUTPUT);
  //  digitalWrite(BLANK, LOW);

  Serial.begin(115200);
  delay(1000);
  Serial.println("\r\nVectorboy Booted!!");

  // 16kHz PWM output, 40% high duty cycle
  ledc_timer_config_t ledc_timer;
  ledc_timer.speed_mode = LEDC_HIGH_SPEED_MODE;  // timer mode
  ledc_timer.duty_resolution = LEDC_TIMER_8_BIT; // resolution of PWM duty
  ledc_timer.timer_num = LEDC_TIMER_0;           // timer index
  ledc_timer.freq_hz = 16000;                    // frequency of PWM signal
  // Set configuration of timer0 for high speed channels
  esp_err_t result = ledc_timer_config(&ledc_timer);
  if (result == ESP_OK) {
    Serial.printf("frequency: %d", ledc_get_freq(LEDC_HIGH_SPEED_MODE, LEDC_TIMER_0));
  }
  ledc_channel_config_t ledc_channel = {
    .gpio_num   = 19, // GPIO PIN 19
    .speed_mode = LEDC_HIGH_SPEED_MODE,
    .channel    = LEDC_CHANNEL_0,
    .intr_type  = LEDC_INTR_DISABLE,
    .timer_sel  = LEDC_TIMER_0,
    .duty       = 100,
    .hpoint     = 0
  };
  // Set LED Controller with previously prepared configuration
  ledc_channel_config(&ledc_channel);

  i2s_driver_uninstall((i2s_port_t)i2s_num);
  btStop();
  //initialize i2s with configurations above
  i2s_config.dma_buf_count = 2;
  i2s_config.dma_buf_len = BUFFER_LEN / 2;
  i2s_driver_install((i2s_port_t)i2s_num, &i2s_config, 0, NULL);
  i2s_set_pin((i2s_port_t)i2s_num, &pin_config);
}

float rotation = 0;
uint8_t sw_mode = 1;
uint8_t initialized = 0;

void loop() {
  if (sw_mode != !digitalRead(SWITCH)) {
    delay(30); // crude debounce
    sw_mode = !digitalRead(SWITCH);
    initialized = 0;
  }

  if (sw_mode == 1) { // Lorenz Attactor Mode
    if (!initialized) {
      i2s_driver_uninstall((i2s_port_t)i2s_num);
      btStop();
      //initialize i2s with configurations above
      i2s_config.dma_buf_count = 2;
      i2s_config.dma_buf_len = BUFFER_LEN / 2;
      i2s_driver_install((i2s_port_t)i2s_num, &i2s_config, 0, NULL);
      i2s_set_pin((i2s_port_t)i2s_num, &pin_config);
      initialized = 1;
    }

    fillBuffer(BUFFER_LEN, rotation);
    i2s_write_expand((i2s_port_t)i2s_num, (const char *)&buf, i2s_config.dma_buf_len * 8, 16, 16, &i2s_bytes_written, 100);
    dt = analogRead(TUNE) / 100000.0f;
    rotation = rotation + 0.001;
    if (rotation > M_PI_2 * 720.0) {
      rotation = 0;
    }
  } else { // BT Audio Mode
    if (!initialized) {
      i2s_config.dma_buf_count = 32;
      i2s_config.dma_buf_len = 256;
      i2s_driver_uninstall((i2s_port_t)i2s_num);
      a2dp_sink.set_pin_config(pin_config);
      a2dp_sink.set_i2s_config(i2s_config);
      a2dp_sink.start("Vectorboy");
      initialized = 1;
    }
  }
}

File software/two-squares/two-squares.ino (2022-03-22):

/*
  TWO SQUARES

  Driving deflection coils with an external DAC using ESP32

  Copyright (C) 2020-2022 Niklas Fauth, Technobly
  This program is free software: you can redistribute it and/or modify
  it under the terms of the GNU General Public License as published by
  the Free Software Foundation, either version 3 of the License, or
  (at your option) any later version.
  This program is distributed in the hope that it will be useful,
  but WITHOUT ANY WARRANTY; without even the implied warranty of
  MERCHANTABILITY or FITNESS FOR A PARTICULAR PURPOSE.  See the
  GNU General Public License for more details.
  You should have received a copy of the GNU General Public License
  along with this program.  If not, see <http://www.gnu.org/licenses/>.
*/

#include "BluetoothA2DPSink.h"
#include <Arduino.h>
#include "driver/i2s.h"
#include "driver/ledc.h"

BluetoothA2DPSink a2dp_sink;

#define CODEC_EN   13
#define SPEAKER_EN 18
#define FLYBACK    19
#define TUNE       34
#define SWITCH     22 // This changes the mode of operation. 1 = BT Audio; 0 = Lorentz Attractor Simulation
#define BLANK      25 // Blanking pin

#define BUFFER_LEN 80

uint32_t buf[BUFFER_LEN];

int i2s_num = 0;
size_t i2s_bytes_written = 0;

i2s_config_t i2s_config = {
  .mode = (i2s_mode_t) (I2S_MODE_MASTER | I2S_MODE_TX),
  .sample_rate = 50000,
  .bits_per_sample = (i2s_bits_per_sample_t)16,
  .channel_format = I2S_CHANNEL_FMT_RIGHT_LEFT,
  .communication_format = (i2s_comm_format_t) (I2S_COMM_FORMAT_STAND_I2S),
  .intr_alloc_flags = 0, // default interrupt priority
  .dma_buf_count = 2,
  .dma_buf_len = 256,
  .use_apll = false
};

static const i2s_pin_config_t pin_config = {
  .bck_io_num = 12,
  .ws_io_num = 27,
  .data_out_num = 14,
  .data_in_num = I2S_PIN_NO_CHANGE
};

uint32_t calc_buf_pos(int16_t x, int16_t y) { // +/- 1024
  uint16_t x_i = x * 2;
  uint16_t y_i = y * 2;
  uint32_t buf;

  buf = x_i | y_i << 16;
  return buf;
}

void drawStuff(uint16_t sz) {

  static int x_off = -1024;
  static int y_off = -1024;
  static int dir = 0;

  switch (dir) {
    case 0: {
        if (y_off < 1024) {
          y_off++;
          x_off = -1024;
        } else {
          dir = 1;
        }
        break;
      }
    case 1: {
        if (x_off < 1024) {
          x_off++;
          y_off = 1024;
        } else {
          dir = 2;
        }
        break;
      }
    case 2: {
        if (y_off > -1024) {
          y_off--;
          x_off = 1024;
        } else {
          dir = 3;
        }
        break;
      }
    case 3: {
        if (x_off > -1024) {
          x_off--;
          y_off = -1024;
        } else {
          dir = 0;
        }
        break;
      }
  };

  buf[0] = calc_buf_pos(-500 + x_off, -500 + y_off); // 1
  buf[1] = calc_buf_pos(-500 + x_off, -400 + y_off);
  buf[2] = calc_buf_pos(-500 + x_off, -300 + y_off);
  buf[3] = calc_buf_pos(-500 + x_off, -200 + y_off);
  buf[4] = calc_buf_pos(-500 + x_off, -100 + y_off);
  buf[5] = calc_buf_pos(-500 + x_off, 0 + y_off);
  buf[6] = calc_buf_pos(-500 + x_off, 100 + y_off);
  buf[7] = calc_buf_pos(-500 + x_off, 200 + y_off);
  buf[8] = calc_buf_pos(-500 + x_off, 300 + y_off);
  buf[9] = calc_buf_pos(-500 + x_off, 400 + y_off);
  buf[10] = calc_buf_pos(-500 + x_off, 500 + y_off); // 2

  buf[11] = calc_buf_pos(-400 + x_off, 500 + y_off);
  buf[12] = calc_buf_pos(-300 + x_off, 500 + y_off);
  buf[13] = calc_buf_pos(-200 + x_off, 500 + y_off);
  buf[14] = calc_buf_pos(-100 + x_off, 500 + y_off);
  buf[15] = calc_buf_pos(0 + x_off, 500 + y_off);
  buf[16] = calc_buf_pos(100 + x_off, 500 + y_off);
  buf[17] = calc_buf_pos(200 + x_off, 500 + y_off);
  buf[18] = calc_buf_pos(300 + x_off, 500 + y_off);
  buf[19] = calc_buf_pos(400 + x_off, 500 + y_off);
  buf[20] = calc_buf_pos(500 + x_off, 500 + y_off); // 3

  buf[21] = calc_buf_pos(500 + x_off, 400 + y_off);
  buf[22] = calc_buf_pos(500 + x_off, 300 + y_off);
  buf[23] = calc_buf_pos(500 + x_off, 200 + y_off);
  buf[24] = calc_buf_pos(500 + x_off, 100 + y_off);
  buf[25] = calc_buf_pos(500 + x_off, 0 + y_off);
  buf[26] = calc_buf_pos(500 + x_off, -100 + y_off);
  buf[27] = calc_buf_pos(500 + x_off, -200 + y_off);
  buf[28] = calc_buf_pos(500 + x_off, -300 + y_off);
  buf[29] = calc_buf_pos(500 + x_off, -400 + y_off);
  buf[30] = calc_buf_pos(500 + x_off, -500 + y_off); // 4

  buf[31] = calc_buf_pos(400 + x_off, -500 + y_off);
  buf[32] = calc_buf_pos(300 + x_off, -500 + y_off);
  buf[33] = calc_buf_pos(200 + x_off, -500 + y_off);
  buf[34] = calc_buf_pos(100 + x_off, -500 + y_off);
  buf[35] = calc_buf_pos(0 + x_off, -500 + y_off);
  buf[36] = calc_buf_pos(-100 + x_off, -500 + y_off);
  buf[37] = calc_buf_pos(-200 + x_off, -500 + y_off);
  buf[38] = calc_buf_pos(-300 + x_off, -500 + y_off);
  buf[39] = calc_buf_pos(-400 + x_off, -500 + y_off);

  buf[40] = calc_buf_pos(-500 + -x_off, -500 + -y_off); // 1
  buf[41] = calc_buf_pos(-500 + -x_off, -400 + -y_off);
  buf[42] = calc_buf_pos(-500 + -x_off, -300 + -y_off);
  buf[43] = calc_buf_pos(-500 + -x_off, -200 + -y_off);
  buf[44] = calc_buf_pos(-500 + -x_off, -100 + -y_off);
  buf[45] = calc_buf_pos(-500 + -x_off, 0 + -y_off);
  buf[46] = calc_buf_pos(-500 + -x_off, 100 + -y_off);
  buf[47] = calc_buf_pos(-500 + -x_off, 200 + -y_off);
  buf[48] = calc_buf_pos(-500 + -x_off, 300 + -y_off);
  buf[49] = calc_buf_pos(-500 + -x_off, 400 + -y_off);
  buf[50] = calc_buf_pos(-500 + -x_off, 500 + -y_off); // 2

  buf[51] = calc_buf_pos(-400 + -x_off, 500 + -y_off);
  buf[52] = calc_buf_pos(-300 + -x_off, 500 + -y_off);
  buf[53] = calc_buf_pos(-200 + -x_off, 500 + -y_off);
  buf[54] = calc_buf_pos(-100 + -x_off, 500 + -y_off);
  buf[55] = calc_buf_pos(0 + -x_off, 500 + -y_off);
  buf[56] = calc_buf_pos(100 + -x_off, 500 + -y_off);
  buf[57] = calc_buf_pos(200 + -x_off, 500 + -y_off);
  buf[58] = calc_buf_pos(300 + -x_off, 500 + -y_off);
  buf[59] = calc_buf_pos(400 + -x_off, 500 + -y_off);
  buf[60] = calc_buf_pos(500 + -x_off, 500 + -y_off); // 3

  buf[61] = calc_buf_pos(500 + -x_off, 400 + -y_off);
  buf[62] = calc_buf_pos(500 + -x_off, 300 + -y_off);
  buf[63] = calc_buf_pos(500 + -x_off, 200 + -y_off);
  buf[64] = calc_buf_pos(500 + -x_off, 100 + -y_off);
  buf[65] = calc_buf_pos(500 + -x_off, 0 + -y_off);
  buf[66] = calc_buf_pos(500 + -x_off, -100 + -y_off);
  buf[67] = calc_buf_pos(500 + -x_off, -200 + -y_off);
  buf[68] = calc_buf_pos(500 + -x_off, -300 + -y_off);
  buf[69] = calc_buf_pos(500 + -x_off, -400 + -y_off);
  buf[70] = calc_buf_pos(500 + -x_off, -500 + -y_off); // 4
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

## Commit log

2022-02-19 adds LCSC compatible BOM and README.md for how to order
    [LCSC-Bom-Vectorboy-v1.0.csv, LCSC-Exported-Vectorboy-v1.0.csv]
2022-03-21 update boms with errors found during build.
    Everything should work now if building from the bags of parts you receive
    [LCSC-Bom-Vectorboy-v1.0.csv, LCSC-Exported-Vectorboy-v1.0.csv]
2022-03-22 more updates to README.md and BOM
    [LCSC-Bom-Vectorboy-v1.0.csv]
2022-03-22 fix/update software PWM/warnings, add more examples
    [bt_music_receiver_to_dac.ino, one-square.ino, scopeman.ino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]
2022-08-28 add software keystone correction
    [scopeman.ino]
2022-08-29 fixes up some confusing dual footprints - v1.3
    [LCSC-Bom-Vectorboy-v1.0.csv, LCSC-Exported-Vectorboy-v1.0.csv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]
2022-08-29 Make all Vectorboy files v1.3 to keep things aligned
    [LCSC-Bom-Vectorboy-v1.1.csv, LCSC-Exported-Vectorboy-v1.1.csv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]
2022-08-29 [v1.3] fix Q1-Q4 3D render and move BT1/BT2 onto the board
    [sony-scopeman.kicad_pcb]
2022-08-31 fix BOM for importing and building at JLCPCB
    [LCSC-Bom-Vectorboy-v1.3.csv, LCSC-Exported-Condensed-Designators-Vectorboy-v1.3.csv, LCSC-Exported-Vectorboy-v1.3.csv]
